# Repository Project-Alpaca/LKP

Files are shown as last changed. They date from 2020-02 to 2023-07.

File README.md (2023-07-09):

lkp-logo

# LKP

レンくんピアノ (Len-kun Piano)

Capacitive touch slider controller for rhythm games.

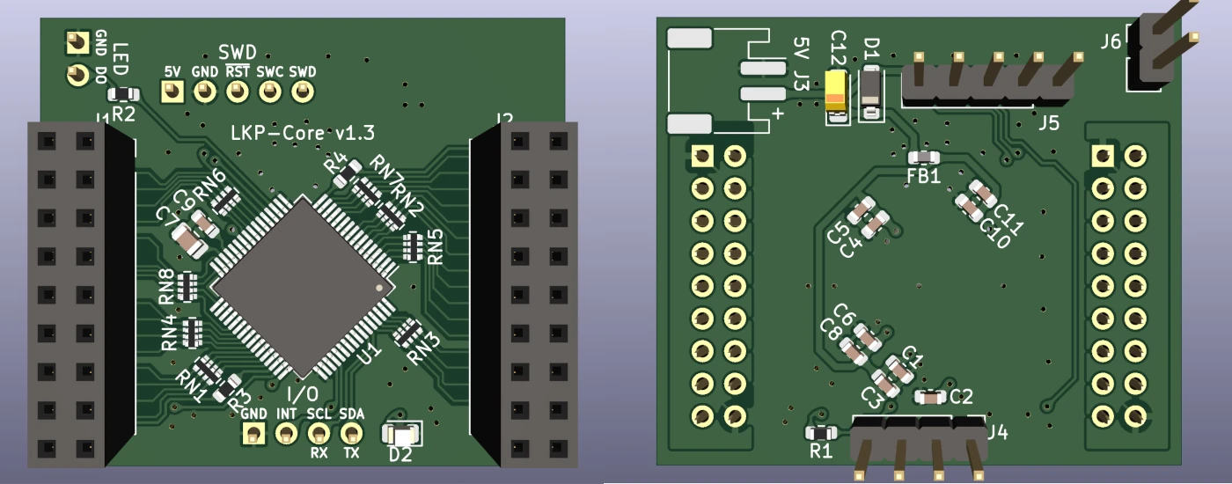
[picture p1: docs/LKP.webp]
LKP


# Contents

## pcb/LKP-Core

Microcontroller board for use with LKP electrode boards. Supports up to 32 channel of self capacitance input. Includes a WS281x LED driver channel with protection resistor. Supports I2C or UART as communication methods.

For sample firmware for use with LKP-Core, see [LKP-FW](https://github.com/Project-Alpaca/LKP-FW).

### Pin mapping

I/O port:

| \#  | Description |
| --- | --- |
|  1  | GND |
|  2  | INT |
|  3  | SCL/RX |
|  4  | SDA/TX |

WS281x LED connector:

| \#  | Description |
| --- | --- |
|  1  | GND |
|  2  | LED |

SWD connector:

| \#  | Description |
| --- | --- |
|  1  | VTARG |
|  2  | GND |
|  3  | RESET |
|  4  | SWCLK |
|  5  | SWDIO |

## pcb/LKP-Core-EasyAccess

**IMPORTANT**: WS281x LED driver will not work on this variant. See errata. This variant is only included for documentation purposes and will no longer receive updates.

A variant of LKP-Core that originally focused on improved accessibility for arcade controller DIY hobbyists with only basic (through hole) soldering skills. All parts used in this variant (once the chip shortage situations improve) are available for use with [JLCPCB Assembly](https://jlcpcb.com/smt-assembly) service, thus enables the possibility of ordering fully assembled and working boards straight from JLCPCB. Even without the assembly service working at the moment, the chip used in this variant can be purchased from LCSC in low quantity for a lot less money compare to the original chip on Digi-key, so it also acts as a budget option without sacrificing performance in significant ways.

## pcb/LKP-Diva-Electrode-Tile

Electrode board for Project DIVA Future Tone slider controller. Works as a 2-tile setup. Both tiles use the same design, with right tile being a 180 degree rotated version of the left tile.

## pcb/LKP-Chu-Electrode-Tile

Electrode board for Chunithm slider controller. Works the same as its LKP-Diva counterpart.

## pcb/LKP-IF-QC

I2C quick connect (compatible with SparkFun [Qwiic®][qwiic] and Adafruit [STEMMA® QT][stemmaqt]) interface for LKP-Core. Goes up to 1MHz for I2C connections and up to 24MHz for UART connections. Converts between 5V logic used by LKP-Core and 3.3V logic used by Qwiic®/STEMMA® QT.

It is also possible to use it to convert UART signal for main microcontroller running between 1.65V and 3.6V. To set it up:

1. Break out the signals on any one of the Qwiic®/STEMMA® QT port on LKP-IF-QC using a Qwiic®/STEMMA® QT breakout board.
2. Connect the 3.3V pin to microcontroller's I/O voltage reference (must be between 1.65V and 3.6V).
3. Connect SDA (blue wire, UART TX) to RX and SCL (yellow wire, UART RX) to TX.
4. The other Qwiic®/STEMMA® QT port should be left unconnected.

Note that although the low side of the level shifter can take any voltage between 1.65V and 3.6V, 3.3V must be used in order to maintain compatibility with other Qwiic®/STEMMA® QT-compatible systems.

# BOM

## LKP-Core

- **C1, C4, C6, C10**: Generic 1uF 0603 X5R ceramic capacitor. (I used `CC0603KRX5R8BB105`)
- **C2, C3, C5, C8, C11**: Generic 100nF 0603 ceramic capacitor. (I used `CL10B104KA8NNNC`)
- **C7**: `GRM2195C1H103JA01D`.
- **C9**: `GCM1885C1H222JA16D`.
- **C12**: Generic 10uF EIA-3216-18 tantalum capacitor.
- **D1**: Generic SOD-123 Schottky diode (`MBR0520L`).
- **D2**: Generic 0805 LED (yellow color).
- **FB1**: Generic 0603 ferrite bead (330ohm@100MHz).
- **J1, J2**: Straight female .1" header 2x9.
- **J3**: JST PH 2 positions.
- **J4**: Straight male .1" header 1x4 (can be angled if not using `LKP-IF-*`).
- **J5**: Straight male .1" header 1x5 (can be angled if not using `LKP-IF-*`).
- **J6**: **Angled** male .1" header 1x2.
- **R1**: Generic 1kohm 5% 0603 resistor.
- **R2**: Generic 470ohm 5% 0603 resistor.
- **R3, R4**: Generic 560ohm 5% 0603 resistor.
- **RN\***: Generic 560ohm 5% 0402x4 convex resistor array (I used `4D02WGJ0561TCE`).
- **U1**: `CY8C4246AZI-M445` (or `CY8C4247AZI-M485`, Needs minor firmware modifications).

## LKP-Diva-Electrode-Tile and LKP-Chu-Electrode-Tile

- **J1**: Straight male .1" SMD header 2x9 (**without** bumps at the bottom).
  - This can be hard to find. For small scale DIY manufacturing try searching "pin header double smd" on aliexpress.

## LKP-IF-QC

- **C1, C2**: Generic 100nF 0603 ceramic capacitor. (I used `CL10B104KA8NNNC`).
- **D1**: Generic SOD-123 Schottky diode (`MBR0520L`).
- **J1, J2**: JST SH SM04B.
- **J3**: Straight female (10.5mm stacking or regular) .1" header 1x5.
- **J4**: Straight female (10.5mm stacking or regular) .1" header 1x4.
- **J5**: Straight or angled male .1" header header 1x2 (Optional if using stacking headers for J3-4).
- **U1**: `TCA9406DCTR`.

# Powering

By default LKP expects 5V power. Using lower supply voltage down to 1.8V is possible by modifying the power specs in LKP-FW and adding a level shifter module to the WS281x driver pin (labeled as LED on board). Reference voltage for I/O can be approximated by tapping into the VTARG pin on the SWD port.

# Known issues / Erratas

- (LKP-Core v1.0) The reverse voltage protection diode (D1) does not protect C12. Proceed with caution when connecting the power to make sure the polarity is correct.
- (LKP-Core v1.1) When used with LKP-Assy, connector J4, J5 and J6 may collide with the bottom of LKP-Assy. A workaround would be soldering all the specified connectors on the back side of the PCB instead. Also, when using LKP-IF-Qwiic, J4 and J5 must be soldered on the back side.
- (LKP-Core-EasyAccess v1.2-E) Due to an oversight when choosing chips for this board, it lacks the necessary hardware features for the WS281x driver pin to function (i.e. UDB). A software workaround might be possible (with e.g. SPI DMA like FastLED Arduino library) but it might not be cost effective to develop it further.

# Special thanks

- [@pol8139][pol8139]'s [controller build guide](https://pol.booth.pm/items/967132) for pointing me to PSoC as a potential solution and demonstrating the possibility of using a single PSoC 4 to drive the entire slider.
- [@azhao12345][azhao12345] for providing the idea of modular and tiled electrode design.
- [ryun][ryun] and [@somewhatlurker][somewhatlurker] for their reverse-engineering effort on 837-15275/15330 protocol and firmware, which form the basis of LKP-Serial and [sega-slider.md](https://gist.github.com/dogtopus/b61992cfc383434deac5fab11a458597).
- [MarkH_61][markh61] for StripLightLib, which saved me quite a bit of headache of figuring out how to use UDB/datapath to drive huge array of NeoPixels without starving the CPU.

[qwiic]: https://www.sparkfun.com/qwiic
[stemmaqt]: https://learn.adafruit.com/introducing-adafruit-stemma-qt/what-is-stemma-qt
[pol8139]: https://github.com/pol8139/
[azhao12345]: https://gitlab.com/azhao12345/
[ryun]: https://ryun.halfmoon.jp/touchslider/slider_protocol.html
[markh61]: https://community.cypress.com/thread/16543
[somewhatlurker]: https://github.com/somewhatlurker

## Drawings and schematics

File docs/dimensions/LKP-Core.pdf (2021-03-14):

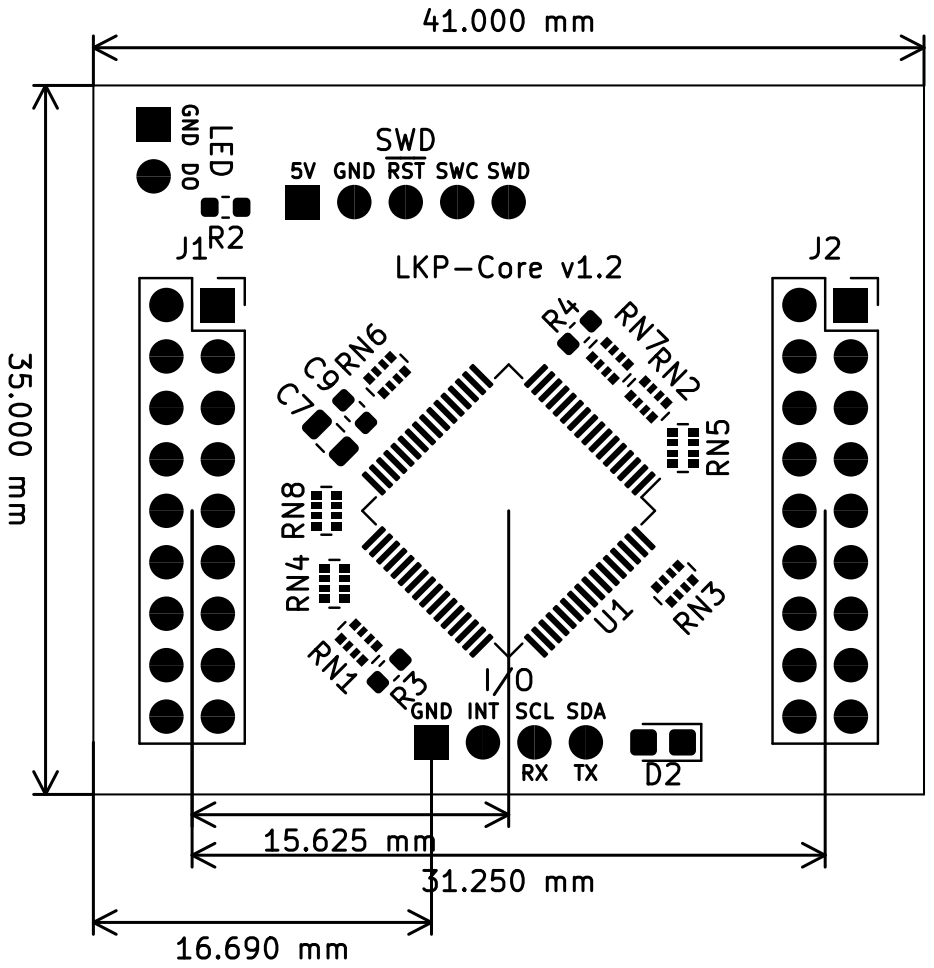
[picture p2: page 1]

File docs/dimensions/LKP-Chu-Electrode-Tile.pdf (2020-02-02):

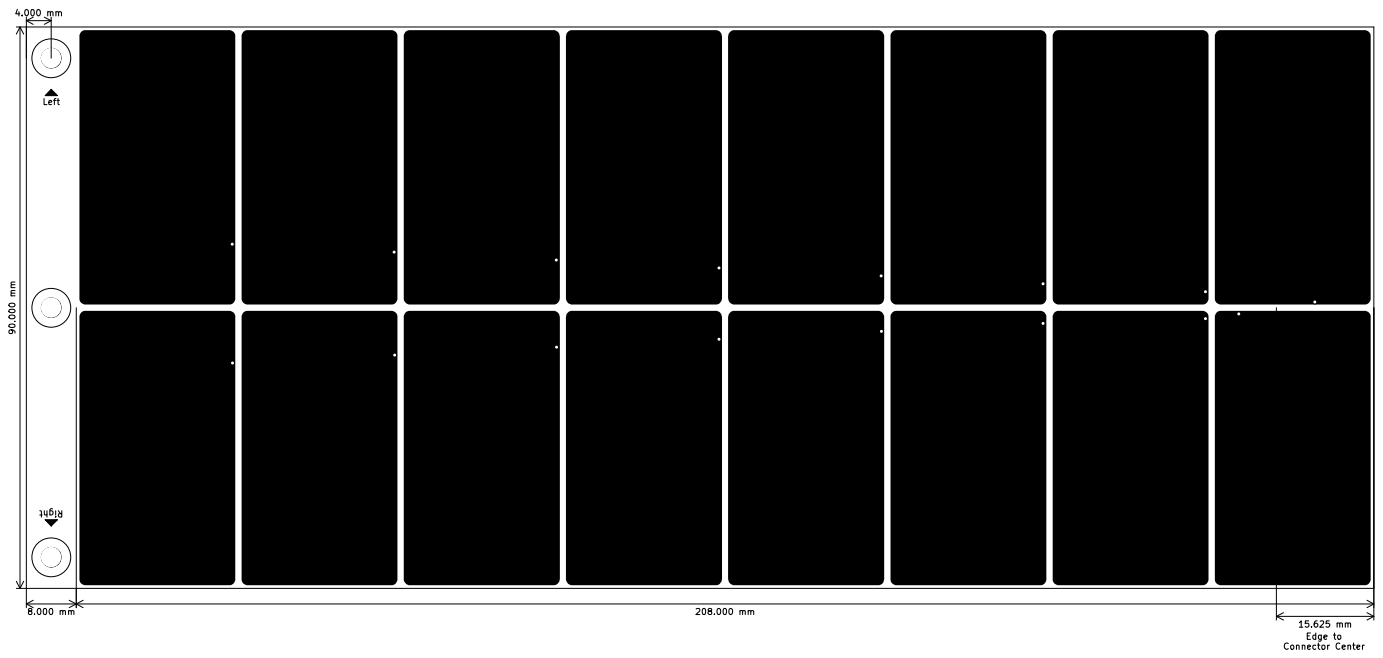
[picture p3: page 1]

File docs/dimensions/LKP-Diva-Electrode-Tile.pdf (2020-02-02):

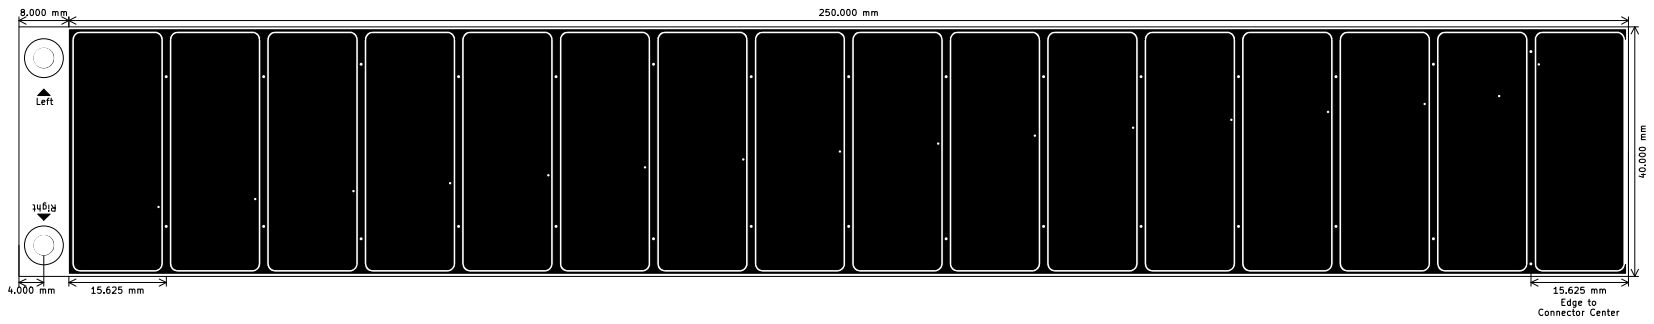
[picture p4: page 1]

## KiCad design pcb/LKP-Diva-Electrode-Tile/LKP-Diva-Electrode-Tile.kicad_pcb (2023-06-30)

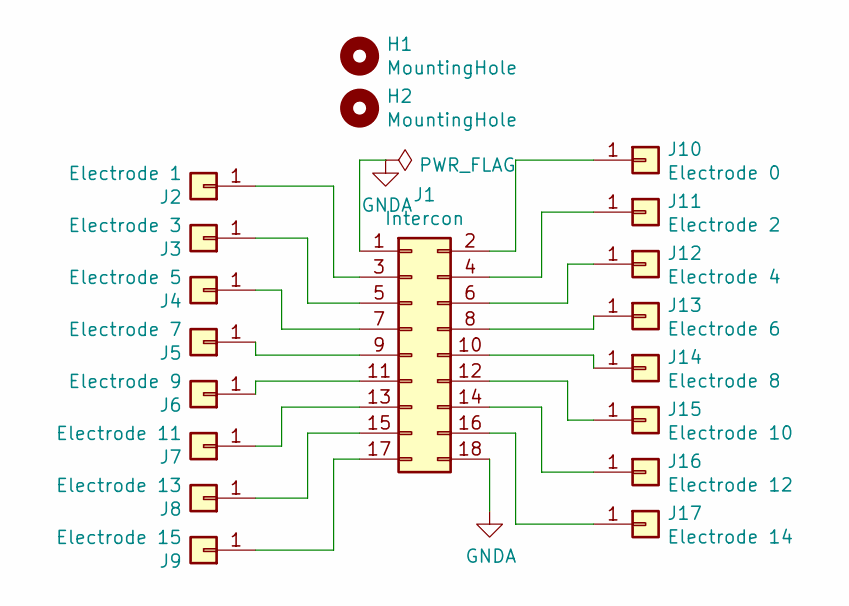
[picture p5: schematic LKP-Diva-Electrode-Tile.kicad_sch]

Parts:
H1, H2: MountingHole; MountingHole_3.2mm_M3_ISO7380
J1: Intercon; PinHeader_2x09_P2.54mm_Vertical_SMD
J2: Electrode 1; CapSense_Electrode_14.6x39mm
J3: Electrode 3; CapSense_Electrode_14.6x39mm
J4: Electrode 5; CapSense_Electrode_14.6x39mm
J5: Electrode 7; CapSense_Electrode_14.6x39mm
J6: Electrode 9; CapSense_Electrode_14.6x39mm
J7: Electrode 11; CapSense_Electrode_14.6x39mm
J8: Electrode 13; CapSense_Electrode_14.6x39mm
J9: Electrode 15; CapSense_Electrode_14.6x39mm
J10: Electrode 0; CapSense_Electrode_14.6x39mm
J11: Electrode 2; CapSense_Electrode_14.6x39mm
J12: Electrode 4; CapSense_Electrode_14.6x39mm
J13: Electrode 6; CapSense_Electrode_14.6x39mm
J14: Electrode 8; CapSense_Electrode_14.6x39mm
J15: Electrode 10; CapSense_Electrode_14.6x39mm
J16: Electrode 12; CapSense_Electrode_14.6x39mm
J17: Electrode 14; CapSense_Electrode_14.6x39mm

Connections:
GNDA: J1.1, J1.18
unnamed: J1.2, J10.1
unnamed: J1.3, J2.1
unnamed: J1.4, J11.1
unnamed: J1.5, J3.1
unnamed: J1.6, J12.1
unnamed: J1.7, J4.1
unnamed: J1.8, J13.1
unnamed: J1.9, J5.1
unnamed: J1.10, J14.1
unnamed: J1.11, J6.1
unnamed: J1.12, J15.1
unnamed: J1.13, J7.1
unnamed: J1.14, J16.1
unnamed: J1.15, J8.1
unnamed: J1.16, J17.1
unnamed: J1.17, J9.1

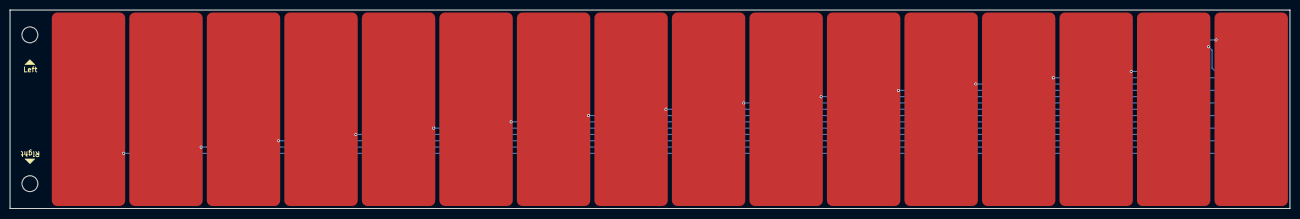
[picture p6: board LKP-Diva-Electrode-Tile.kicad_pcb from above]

Board: 2 copper layers, 258.0 x 40.0 mm, 19 parts (1 on the bottom side), 17 nets.

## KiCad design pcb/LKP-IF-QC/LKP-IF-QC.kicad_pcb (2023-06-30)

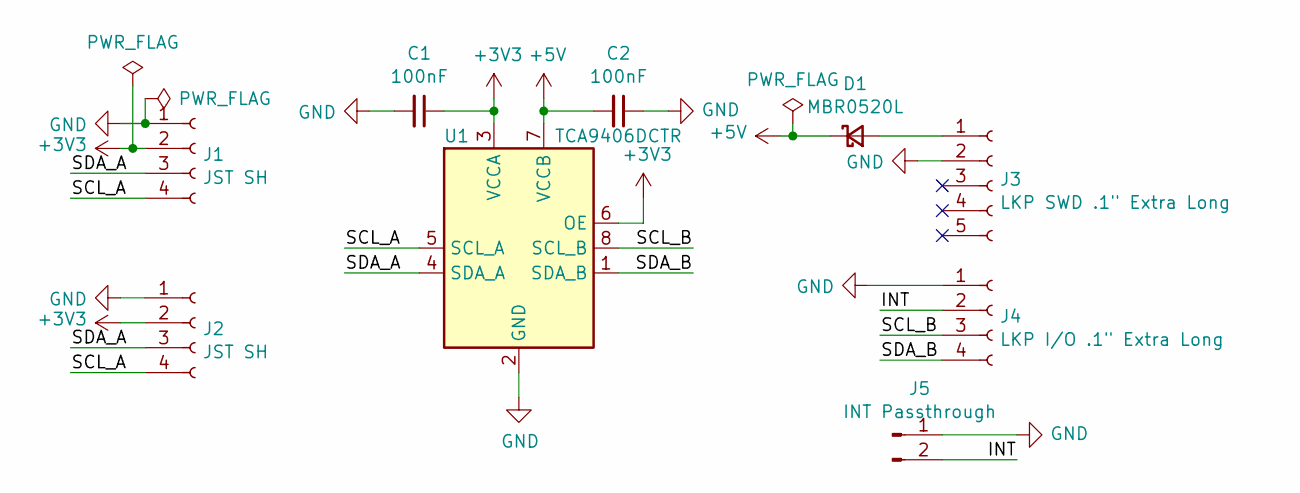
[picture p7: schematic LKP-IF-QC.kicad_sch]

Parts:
C1, C2: 100nF; C_0603_1608Metric
D1: MBR0520L; D_SOD-123
J1, J2: JST SH; JST_SH_SM04B-SRSS-TB_1x04-1MP_P1.00mm_Horizontal
J3: LKP SWD .1" Extra Long; PinSocket_1x05_P2.54mm_Vertical
J4: LKP I/O .1" Extra Long; PinSocket_1x04_P2.54mm_Vertical
J5: INT Passthrough; PinHeader_1x02_P2.54mm_Vertical
U1: TCA9406DCTR; SSOP-8_2.95x2.8mm_P0.65mm

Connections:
+3V3: C1.1, J1.2, J2.2, U1.3 (VCCA), U1.6 (OE)
+5V: C2.2, D1.1 (K), U1.7 (VCCB)
/INT: J4.2, J5.2
/SCL_A: J1.4, J2.4, U1.5 (SCL_A)
/SCL_B: J4.3, U1.8 (SCL_B)
/SDA_A: J1.3, J2.3, U1.4 (SDA_A)
/SDA_B: J4.4, U1.1 (SDA_B)
GND: C1.2, C2.1, J1.1, J2.1, J3.2, J4.1, J5.1, U1.2 (GND)
unnamed: D1.2 (A), J3.1

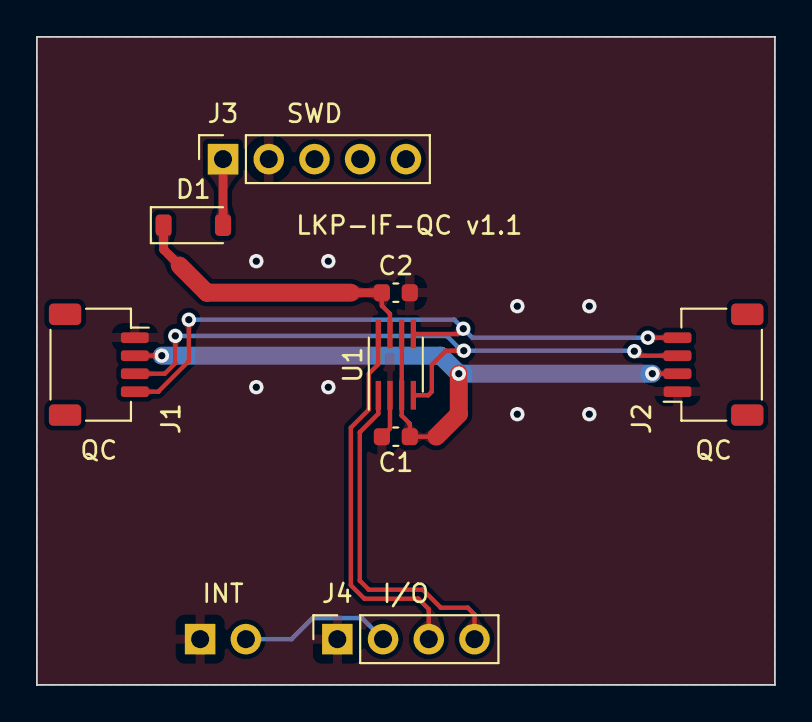
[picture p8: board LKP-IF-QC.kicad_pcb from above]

Board: 2 copper layers, 41.0 x 36.0 mm, 9 parts (1 on the bottom side), 9 nets.

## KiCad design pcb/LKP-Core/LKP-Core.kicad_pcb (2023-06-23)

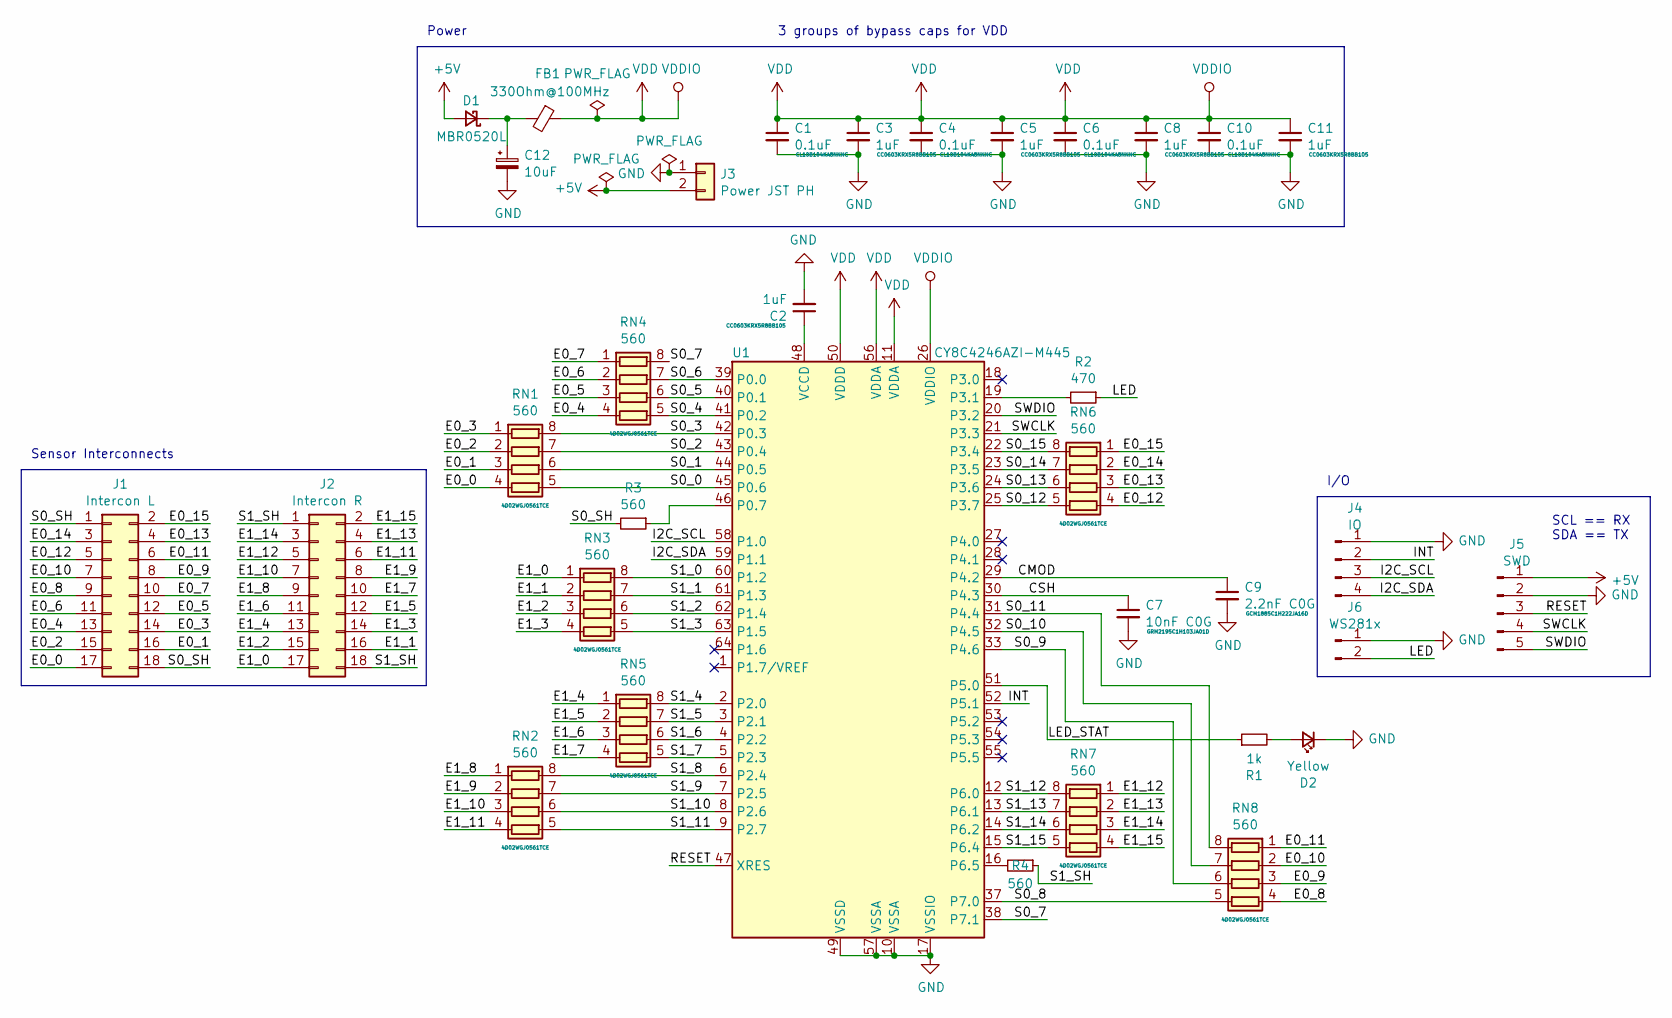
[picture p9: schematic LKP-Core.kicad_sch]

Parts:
C1, C4, C6, C10: 0.1uF; C_0603_1608Metric; Part Number CL10B104KA8NNNC
C2, C3, C5, C8, C11: 1uF; C_0603_1608Metric; Part Number CC0603KRX5R8BB105
C7: 10nF C0G; C_0805_2012Metric; Part Number GRM2195C1H103JA01D
C9: 2.2nF C0G; C_0603_1608Metric; Part Number GCM1885C1H222JA16D
C12: 10uF; CP_EIA-3216-18_Kemet-A
D1: MBR0520L; D_SOD-123; Part Number MBR0520L
D2: Yellow; LED_0805_2012Metric
FB1: 330Ohm@100MHz; L_0603_1608Metric
J1: Intercon L; PinSocket_2x09_P2.54mm_Vertical
J2: Intercon R; PinSocket_2x09_P2.54mm_Vertical
J3: Power JST PH; JST_PH_S2B-PH-SM4-TB_1x02-1MP_P2.00mm_Horizontal
J4: IO; PinHeader_1x04_P2.54mm_Vertical
J5: SWD; PinHeader_1x05_P2.54mm_Vertical
J6: WS281x; PinHeader_1x02_P2.54mm_Vertical
R1: 1k; R_0603_1608Metric
R2: 470; R_0603_1608Metric
R3, R4: 560; R_0603_1608Metric
RN1, RN2, RN3, RN4, RN5, RN6, RN7, RN8: 560; R_Array_Convex_4x0402; Part Number 4D02WGJ0561TCE
U1: CY8C4246AZI-M445; TQFP-64_10x10mm_P0.5mm; Part Number CY8C4246AZI-M445

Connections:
+5V: D1.2 (A), J3.2, J5.1
/CMOD: C9.1, U1.29 (P4.2)
/CSH: C7.1, U1.30 (P4.3)
/E0_0: J1.17, RN1.4 (R4.1)
/E0_1: J1.16, RN1.3 (R3.1)
/E0_2: J1.15, RN1.2 (R2.1)
/E0_3: J1.14, RN1.1 (R1.1)
/E0_4: J1.13, RN4.4 (R4.1)
/E0_5: J1.12, RN4.3 (R3.1)
/E0_6: J1.11, RN4.2 (R2.1)
/E0_7: J1.10, RN4.1 (R1.1)
/E0_8: J1.9, RN8.4 (R4.1)
/E0_9: J1.8, RN8.3 (R3.1)
/E0_10: J1.7, RN8.2 (R2.1)
/E0_11: J1.6, RN8.1 (R1.1)
/E0_12: J1.5, RN6.4 (R4.1)
/E0_13: J1.4, RN6.3 (R3.1)
/E0_14: J1.3, RN6.2 (R2.1)
/E0_15: J1.2, RN6.1 (R1.1)
/E1_0: J2.17, RN3.1 (R1.1)
/E1_1: J2.16, RN3.2 (R2.1)
/E1_2: J2.15, RN3.3 (R3.1)
/E1_3: J2.14, RN3.4 (R4.1)
/E1_4: J2.13, RN5.1 (R1.1)
/E1_5: J2.12, RN5.2 (R2.1)
/E1_6: J2.11, RN5.3 (R3.1)
/E1_7: J2.10, RN5.4 (R4.1)
/E1_8: J2.9, RN2.1 (R1.1)
/E1_9: J2.8, RN2.2 (R2.1)
/E1_10: J2.7, RN2.3 (R3.1)
/E1_11: J2.6, RN2.4 (R4.1)
/E1_12: J2.5, RN7.1 (R1.1)
/E1_13: J2.4, RN7.2 (R2.1)
/E1_14: J2.3, RN7.3 (R3.1)
/E1_15: J2.2, RN7.4 (R4.1)
/I2C_SCL: J4.3, U1.58 (P1.0)
/I2C_SDA: J4.4, U1.59 (P1.1)
/INT: J4.2, U1.52 (P5.1)
/LED: J6.2, R2.1
/LED_STAT: R1.1, U1.51 (P5.0)
/RESET: J5.3, U1.47 (XRES)
/S0_0: RN1.5 (R4.2), U1.45 (P0.6)
/S0_1: RN1.6 (R3.2), U1.44 (P0.5)
/S0_2: RN1.7 (R2.2), U1.43 (P0.4)
/S0_3: RN1.8 (R1.2), U1.42 (P0.3)
/S0_4: RN4.5 (R4.2), U1.41 (P0.2)
/S0_5: RN4.6 (R3.2), U1.40 (P0.1)
/S0_6: RN4.7 (R2.2), U1.39 (P0.0)
/S0_7: RN4.8 (R1.2), U1.38 (P7.1)
/S0_8: RN8.5 (R4.2), U1.37 (P7.0)
/S0_9: RN8.6 (R3.2), U1.33 (P4.6)
/S0_10: RN8.7 (R2.2), U1.32 (P4.5)
/S0_11: RN8.8 (R1.2), U1.31 (P4.4)
/S0_12: RN6.5 (R4.2), U1.25 (P3.7)
/S0_13: RN6.6 (R3.2), U1.24 (P3.6)
/S0_14: RN6.7 (R2.2), U1.23 (P3.5)
/S0_15: RN6.8 (R1.2), U1.22 (P3.4)
/S0_SH: J1.1, J1.18, R3.2
/S1_0: RN3.8 (R1.2), U1.60 (P1.2)
/S1_1: RN3.7 (R2.2), U1.61 (P1.3)
/S1_2: RN3.6 (R3.2), U1.62 (P1.4)
/S1_3: RN3.5 (R4.2), U1.63 (P1.5)
/S1_4: RN5.8 (R1.2), U1.2 (P2.0)
/S1_5: RN5.7 (R2.2), U1.3 (P2.1)
/S1_6: RN5.6 (R3.2), U1.4 (P2.2)
/S1_7: RN5.5 (R4.2), U1.5 (P2.3)
/S1_8: RN2.8 (R1.2), U1.6 (P2.4)
/S1_9: RN2.7 (R2.2), U1.7 (P2.5)
/S1_10: RN2.6 (R3.2), U1.8 (P2.6)
/S1_11: RN2.5 (R4.2), U1.9 (P2.7)
/S1_12: RN7.8 (R1.2), U1.12 (P6.0)
/S1_13: RN7.7 (R2.2), U1.13 (P6.1)
/S1_14: RN7.6 (R3.2), U1.14 (P6.2)
/S1_15: RN7.5 (R4.2), U1.15 (P6.4)
/S1_SH: J2.1, J2.18, R4.1
/SWCLK: J5.4, U1.21 (P3.3)
/SWDIO: J5.5, U1.20 (P3.2)
GND: C1.2, C2.2, C3.2, C4.2, C5.2, C6.2, C7.2, C8.2, C9.2, C10.2, C11.2, C12.2, D2.1 (K), J3.1, J4.1, J5.2, J6.1, U1.10 (VSSA), U1.17 (VSSIO), U1.49 (VSSD), U1.57 (VSSA)
unnamed: C12.1, D1.1 (K), FB1.2
unnamed: D2.2 (A), R1.2
unnamed: R3.1, U1.46 (P0.7)
unnamed: R2.2, U1.19 (P3.1)
unnamed: R4.2, U1.16 (P6.5)
unnamed: C2.1, U1.48 (VCCD)
VDD: C1.1, C3.1, C4.1, C5.1, C6.1, C8.1, C10.1, C11.1, FB1.1, U1.11 (VDDA), U1.26 (VDDIO), U1.50 (VDDD), U1.56 (VDDA)

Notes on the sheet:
Sensor Interconnects
I/O
SCL == RX SDA == TX
Power
3 groups of bypass caps for VDD

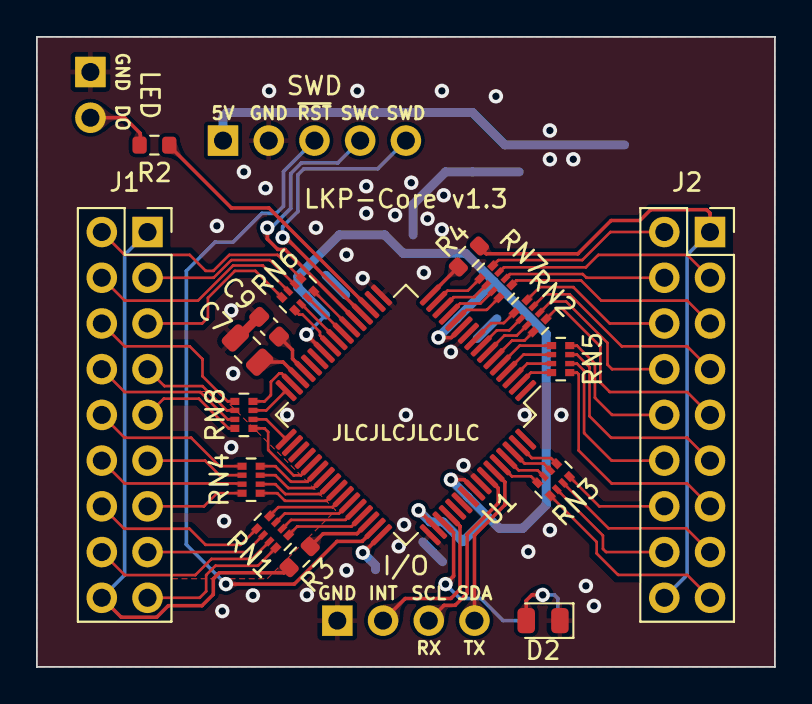
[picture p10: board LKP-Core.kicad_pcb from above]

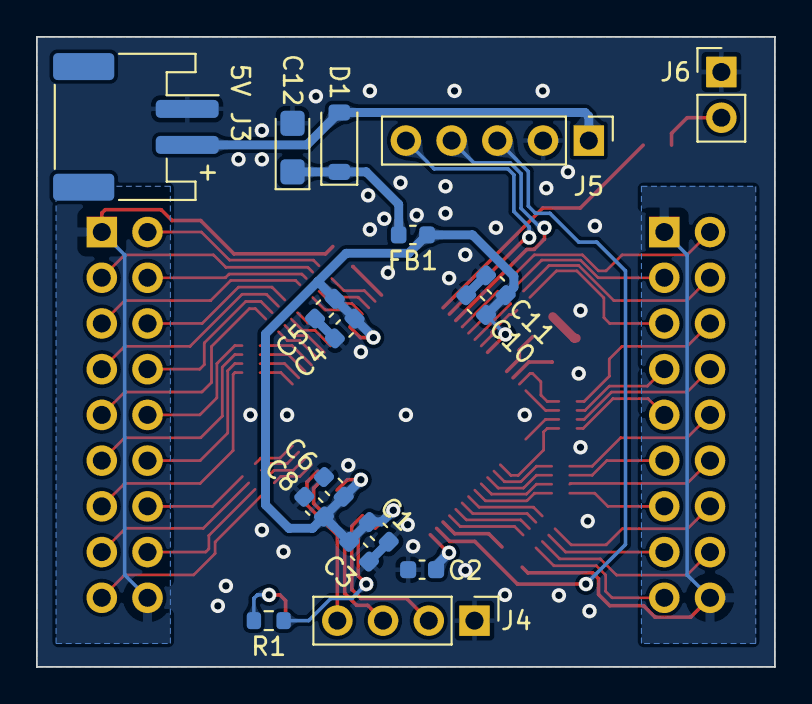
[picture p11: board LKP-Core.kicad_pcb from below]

Board: 2 copper layers, 41.0 x 35.0 mm, 34 parts (17 on the bottom side), 85 nets.

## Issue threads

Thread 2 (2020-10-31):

LKP-Core v1.2 TODO list

dogtopus, 2020-10-31:
- [ ] Slightly increase vertical board size (do we still need this?)
- [x] Move all non-sensor connectors to the back side
- [x] Better labeling

Closed 2021-03-14.

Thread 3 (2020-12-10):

LKP-M39v2

dogtopus, 2020-12-10:
Pop'n Music Welcom to Wonderland slider controller.

Currently known info and ideas:

- 45x8 addressable RGB LED matrix as backlight
  - Maybe possible to implement as a hollowed out sensor board and a dedicated WS281x board/strip array
- Probably needs to put LKP in CSX mode to achieve the resolution
- More info to come

dogtopus, 2021-12-25:
Close this until we got more info.

Closed 2021-12-25.

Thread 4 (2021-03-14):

Convert schematics of LKP-*-Electrode-Tile to new format

dogtopus, 2021-03-14:
So they can be loaded directly by KiCad nightly without the need to convert them every time.

dogtopus, 2021-03-21:
Done.

Closed 2021-03-21.

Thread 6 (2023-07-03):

LKP-Core-2040

dogtopus, 2023-07-03:
Yet another cheap+JLCPCBAble attempt. Uses RP2040+CY8CMBR3116-LQXI. Will likely have a different firmware than LKP-Core due to significant architecture change.

- [ ] Initial feasibility study
  - Datasheet for [CY8CMBR3116-LQXI](https://www.infineon.com/dgdl/Infineon-CY8CMBR3002_CY8CMBR3102_CY8CMBR3106S_CY8CMBR3108_CY8CMBR3110_CY8CMBR3116-DataSheet-v18_00-EN.pdf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)
- [ ] Schematics
- [ ] Firmware PoC
- [ ] Initial PnR
- [ ] PCB Prototype
- [ ] Firmware PoC test

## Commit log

2019-07-27 Initial layout on diva electrode tile
    [LKP-Diva-Electrode-Tile.kicad_pcb, LKP-Diva-Electrode-Tile.sch]
2019-07-29 Start working on LKP-Core
    [LKP-Core.kicad_pcb, LKP-Core.sch]
2019-08-03 Fix sensor topology
    [LKP-Diva-Electrode-Tile.kicad_pcb, LKP-Diva-Electrode-Tile.sch]
2019-08-03 Iteration 1.1 routing
    [LKP-Diva-Electrode-Tile.kicad_pcb]
2019-08-03 Add measurement
    [LKP-Diva-Electrode-Tile.kicad_pcb]
2019-08-03 LKP-Core WIP
    [LKP-Core.sch]
2019-08-04 Finish schematic
    [LKP-Core.sch]
2019-08-04 Misc changes to schematic
    [LKP-Core.sch]
2019-08-04 Fix right shield
    [LKP-Core.sch]
2019-08-05 Initial placement plan
    [LKP-Core.kicad_pcb, LKP-Core.sch]
2019-08-05 Define net classes
    [LKP-Core.kicad_pcb, LKP-Core.sch]
2019-08-05 Power routing plan
    [LKP-Core.kicad_pcb]
2019-08-06 Power line routing
    [LKP-Core.kicad_pcb]
2019-08-06 Sensor routing
    [LKP-Core.kicad_pcb]
2019-08-06 Finishing up
    [LKP-Core.kicad_pcb, LKP-Core.sch]
2019-08-07 Move various IO pins down
    [LKP-Core.sch]
2019-08-07 Apply changes
    [LKP-Core.kicad_pcb, LKP-Core.sch]
2019-08-08 Refactor right side routing
    [LKP-Core.kicad_pcb]
2019-08-08 Finish up
    [LKP-Core.kicad_pcb]
2019-08-08 Some finishing touches
    [LKP-Core.kicad_pcb]
2019-08-08 Fab layer fixes
    [LKP-Core.kicad_pcb]
2019-08-08 Add the status LED back
    [LKP-Core.kicad_pcb, LKP-Core.sch]
2019-08-08 MOAR VIAS
    [LKP-Core.kicad_pcb]
2019-08-09 Add resistors for shield
    [LKP-Core.kicad_pcb, LKP-Core.sch]
2019-08-09 Switch to through hole headers and add a capacitor for good luck
    [LKP-Core.kicad_pcb, LKP-Core.sch]
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2020-01-31 Copy-paste schematic from LKP-Diva with some necessary changes
    [LKP-Chu-Electrode-Tile.kicad_pcb, LKP-Chu-Electrode-Tile.sch]
2020-01-31 Copper fills and fix solder mask on electrodes
    [LKP-Chu-Electrode-Tile.kicad_pcb]
2020-01-31 Place screw holes.
    [LKP-Chu-Electrode-Tile.kicad_pcb, LKP-Chu-Electrode-Tile.sch]
2020-01-31 Finish routing.
    [LKP-Chu-Electrode-Tile.kicad_pcb]
2020-01-31 Add direction indicator.
    [LKP-Chu-Electrode-Tile.kicad_pcb]
2020-02-02 Update board dimension marker
    [LKP-Chu-Electrode-Tile.kicad_pcb, LKP-Diva-Electrode-Tile.kicad_pcb]
2020-02-02 Add dimension PDFs for easier reference
    [LKP-Chu-Electrode-Tile.kicad_pcb, LKP-Diva-Electrode-Tile.kicad_pcb]
2020-09-26 Make reverse voltage protection also work with the tantalum filter cap.
    Bump LKP-Core version number
    [LKP-Core.kicad_pcb, LKP-Core.sch]
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2020-10-24 Add simple BOM and errata section
2020-10-24 Add note about the protection diode issue on LKP-Core v1.0
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2021-03-01 Add schematic for LKP-IF-Qwiic
    [LKP-IF-Qwiic.kicad_pcb, LKP-IF-Qwiic.sch]
2021-03-03 LKP-IF-Qwiic: Add board.
    LKP-Core: Add more measurements.
    [LKP-Core.kicad_pcb, LKP-IF-Qwiic.kicad_pcb, LKP-IF-Qwiic.sch]
2021-03-03 Add info about LKP-IF-Qwiic. Add pin mapping table.
    [LKP-Core.sch]
2021-03-03 Properly define the "3.3V" Qwiic Vref according to TCA9406 datasheet.
2021-03-03 LKP-IF-Qwiic: Add reverse voltage protection.
    [LKP-IF-Qwiic.kicad_pcb, LKP-IF-Qwiic.sch]
2021-03-03 Add reverse voltage protection diode to LKP-IF-Qwiic BOM
2021-03-03 Minor routing adjustment.
    [LKP-IF-Qwiic.kicad_pcb]
2021-03-04 LKP-IF-Qwiic: Add INT passthrough connector as an alternative to stacking headers.
    README: Add notes about how to find the hard-to-find 18-pin male header.
    [LKP-IF-Qwiic.kicad_pcb, LKP-IF-Qwiic.sch]
2021-03-14 LKP-Core: Change schematics so the status LED is directly connected to PSoC pin for better readability.
    [LKP-Core.kicad_pcb, LKP-Core.sch]
2021-03-14 LKP-Core: Add more descriptive silkscreens.
    [LKP-Core.kicad_pcb]
2021-03-14 D -> DO
    [LKP-Core.kicad_pcb]
2021-03-14 LKP-Core: Change minimum mask width and clearance to 0. Slight GND via rearrangements.
    [LKP-Core.kicad_pcb]
2021-03-14 docs: Add LKP-Core dimensions. Update preview pic.
    [LKP-Core.kicad_pcb]
2021-03-21 LKP-Diva-Electrode-Tile: Update to new format.
    - Update hatched fill.
    - Increase the electrode size to 14.6x39mm.
    - Change routing to fit the new pad size.
    - Bump version number.
    [LKP-Diva-Electrode-Tile.kicad_pcb, LKP-Diva-Electrode-Tile.kicad_sch, LKP-Diva-Electrode-Tile.sch]
2021-03-21 Also update LKP-Chu-Electrode-Tile.
    [LKP-Chu-Electrode-Tile.kicad_pcb, LKP-Chu-Electrode-Tile.kicad_sch, LKP-Chu-Electrode-Tile.sch]
2021-03-22 Bump versions for LKP-Chu-Electrode-Tile.
    [LKP-Chu-Electrode-Tile.kicad_pcb]
2021-03-28 Add LKP-Core-EasyAccess.
    It's derived from LKP-Core with all used parts available for use with JLCPCB
    assembly service. Specifically the PSoC is replaced with the newer PSoC 4100S
    series.
    Since JLCPCB still don't support double sided SMD assembly, this will remain
    as not ready for publishing for now.
    [LKP-Core-EasyAccess.kicad_pcb, LKP-Core-EasyAccess.sch]
2021-04-15 LKP-Core: Add top to PSoC measurement.
    [LKP-Core.kicad_pcb]
2021-04-21 Add JLCPCB batch identifier location to LKP-Core.
    [LKP-Core.kicad_pcb]
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2021-07-30 Add notes about the component choosing screwup.
    PSoC 4100S series don't have UDB so WS281x LED driver based on StripLightLib will not work. This variant will probably be discontinued or at least not developed further.
2022-01-02 Update all active projects to KiCad 6.
    [LKP-Chu-Electrode-Tile.kicad_pcb, LKP-Chu-Electrode-Tile.kicad_sch, LKP-Core.kicad_pcb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]
2023-06-23 Update electrode tile projects to KiCad 7
    [LKP-Chu-Electrode-Tile.kicad_pcb, LKP-Chu-Electrode-Tile.kicad_sch, LKP-Diva-Electrode-Tile.kicad_pcb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]
2023-06-23 Minor adjustments to LKP-Core and release v1.3
    - Move LKP-Core to KiCad 7
    - Add teardrop to everything except on intercon connectors.
    - Use regular LED footprint instead of the accidentally added castellated one (somewhat a duplicate of handsoldering but slightly larger)
    - Move to mainline PSoC symbol
    [LKP-Core.kicad_pcb, LKP-Core.kicad_sch]
2023-06-23 Update LKP-IF-Qwiic and bump version to v1.1
    - Rename the project from LKP-IF-Qwiic to LKP-IF-QC since Qwiic isn't the only name for this connector.
    - Move to KiCad 7.
    - Enable teardrops.
    - Minor routing tweaks. No schematic change.
    [LKP-IF-QC.kicad_pcb, LKP-IF-QC.kicad_sch, LKP-IF-Qwiic.kicad_pcb]
2023-06-30 v4.2
    Unify export settings across projects
    [LKP-Chu-Electrode-Tile.kicad_pcb, LKP-Diva-Electrode-Tile.kicad_pcb, LKP-IF-QC.kicad_pcb]
